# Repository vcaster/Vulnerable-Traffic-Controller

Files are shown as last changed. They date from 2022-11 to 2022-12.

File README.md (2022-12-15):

# Vulnerable-Traffic-Controller
## Overview
I built a simulated traffic network with traffic lights that mimics the real world. In addition to the simulation, I created a model train station controlled by traffic lights to illustrate the disaster that occurs when the traffic network is attacked and successfully exploited. The attack was the collision of two trains. Traffic control systems are widely used worldwide to optimize traffic flow, and threat actors can leverage vulnerable systems to cause accidents and disrupt emergency services.
A web interface was built to display varying traffic flow, and a power switch is needed for a traffic operator specialist to perform their role.
The simulated traffic control system was built with a siemens s7 1200 PLC, housing the logical functions of the environment. In addition, an Arduino is attached with an Ethernet Shield w5100, Infrared obstacle avoidance sensors, model trains, and a model railway.

# Paper
* [Building and attacking a traffic controller.pdf](https://github.com/vcaster/Vulnerable-Traffic-Controller/blob/main/Building%20and%20attacking%20a%20traffic%20controller.pdf)
# Images
### Live Action
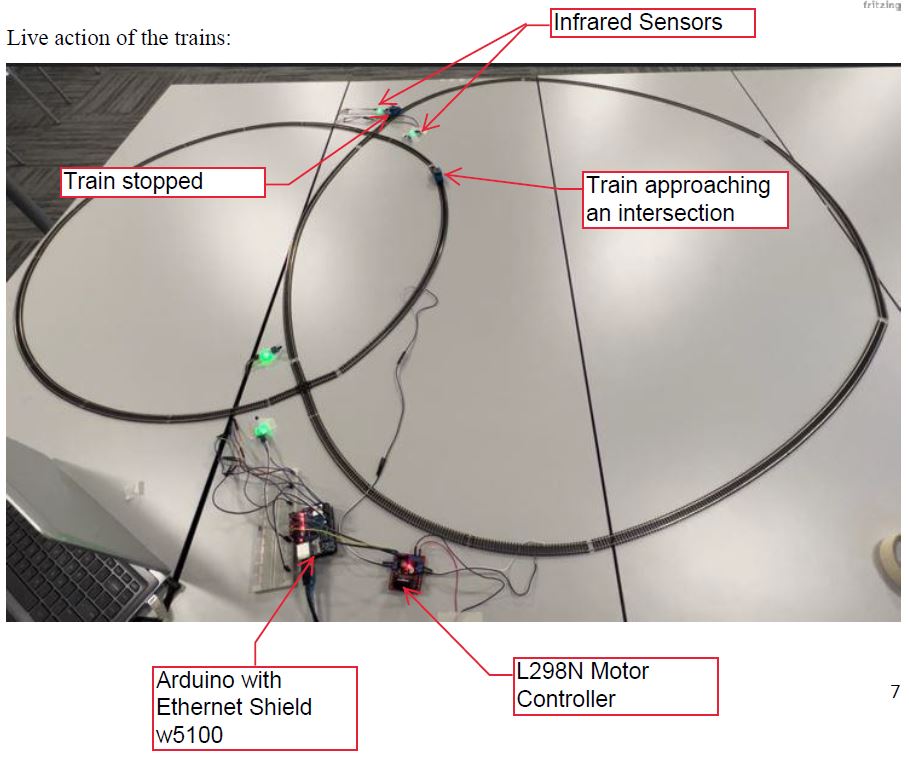
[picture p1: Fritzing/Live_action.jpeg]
Live Action


### PLC Sketch
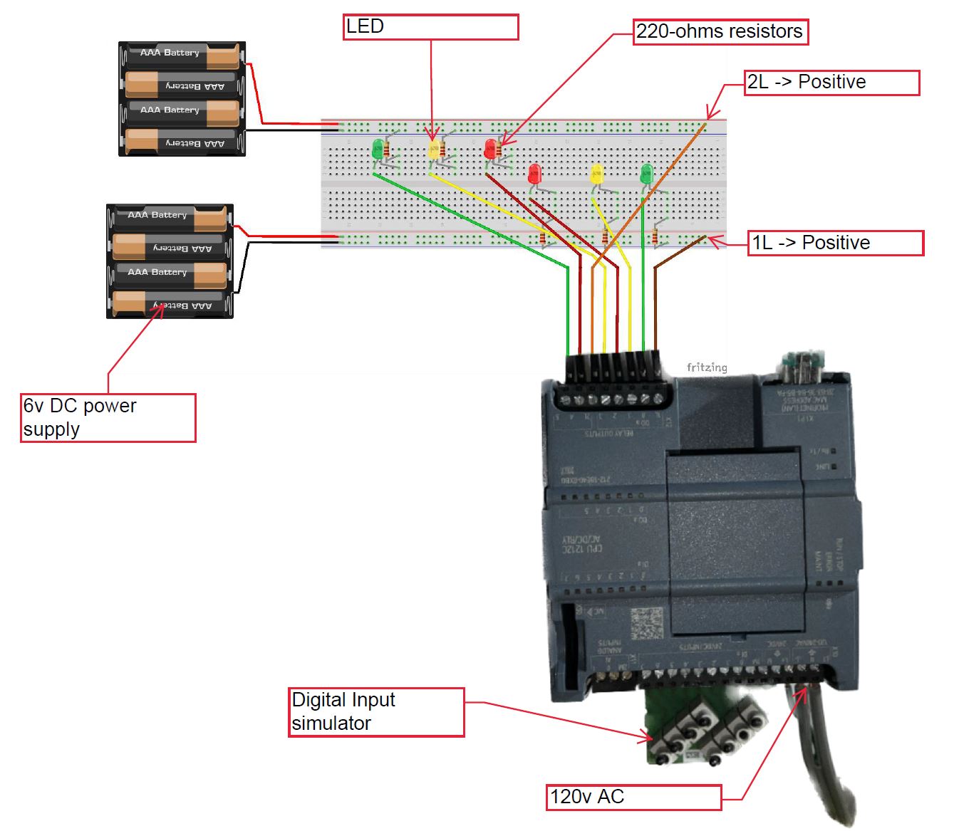
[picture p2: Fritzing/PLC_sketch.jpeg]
PLC Sketch


### Arduino Sketch
PLC Sketch
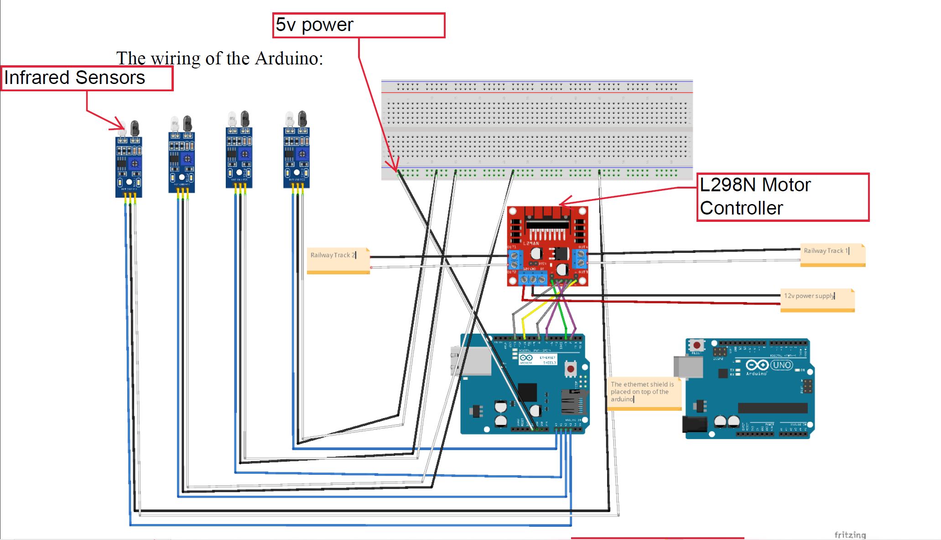
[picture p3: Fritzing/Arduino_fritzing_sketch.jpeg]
Arduino Sketch


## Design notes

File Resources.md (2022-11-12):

# Siemens PLC 

## Programing

* Siemens S7-1200 Video Training Series https://www.youtube.com/playlist?list=PLXgzIIGmsGipySUhEn11-RFaotanAtalO

* Traffic Lights Using PLC Programming https://www.youtube.com/watch?v=mFSuzfGuTHk&t=1s
*

## Modbus

* https://onping.net/bringing-a-siemens-s7-plc-in-to-onping-as-a-modbus-server/
* https://www.solisplc.com/tutorials/modbus-tcp-communications-in-siemens-tia-portal
* https://www.youtube.com/watch?v=POast2vW97A
* https://www.youtube.com/watch?v=6qLv_J2Dk1s
* https://www.youtube.com/watch?v=cjSm5qJfmPg
* https://www.youtube.com/watch?v=NwzBaDsGpic

# Arduino

* Automated Model Train With An Arduino https://www.youtube.com/watch?v=PoOxFS2DNpI&list=WL&index=5&t=8s

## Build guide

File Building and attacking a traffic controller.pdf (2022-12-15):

# Building and attacking a traffic controller:

# SCADA

### Ezekiel O. Aina

### Department of Computer & Information Sciences

### Towson University

### Towson, MD 21252

eaina1@students.towson.edu

Table of Contents

# Overview

The ICS/SCADA industry has been a target for nation-state campaigns, and the need to

understand the attack vector was the goal of this project. I built a simulated traffic network with

traffic lights that mimics the real world. In addition to the simulation, I created a model train

station controlled by traffic lights to illustrate the disaster that occurs when the traffic network is

attacked and successfully exploited. The attack was the collision of two trains. Traffic control

systems are widely used worldwide to optimize traffic flow, and threat actors can leverage

vulnerable systems to cause accidents and disrupt emergency services.

A web interface was built to display varying traffic flow, and a power switch is needed for a

traffic operator specialist to perform their role.

The simulated traffic control system was built with a siemens s7 1200 PLC, housing the logical

functions of the environment. In addition, an Arduino is attached with an Ethernet Shield w5100,

Infrared obstacle avoidance sensors, model trains, and a model railway.

Over the course of this project, I concluded that the MODBUS protocol is insecure, and I

recommend that the protocol be switched to one that includes more layers of security. And if the

system using the MODBUS protocol is a legacy system, then the system must be air-gaped and

layered to restrict access to critical devices.

# Hardware setup

The PLC used for the project is the Siemens SIMATIC S7-1200 (CPU 1212C AC/DC/RLY).

The first PLC is the server updating the traffic sequence and the second acts as a client that syncs

the traffic sequence. I wired the PLC with two sets of traffic lights mapped to the output

addresses on the PLC. The PLC outputs are just relays, and the Orange and brown wires (1L, 2L)

are plugged into positive to complete the circuit. While outputs 0 - 5 are mapped to the green,

yellow, and red lights. The breadboard is powered via a 6v power supply with 220-ohm resistors attached to each LED, and the PLC is powered by 120v. When we get to the software section,

we'll go into how the lights are turned on and the logic behind the timing.

The wiring of the PLC (they are the same for the server and client)

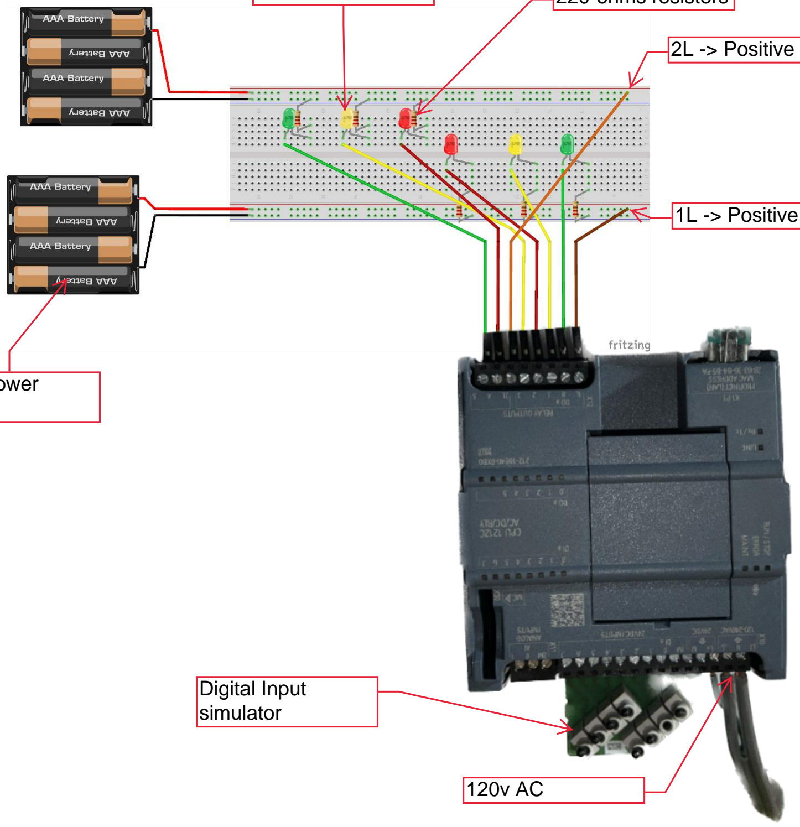
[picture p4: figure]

I faced the problem of simulating the system’s moving parts, which made me consider a remote-

controlled motor with wheels, but the margin of error would be substantial. I finally settled on model trains because it was feasible to control and to forge a path with the railway tracks. Once

the locomotive unit was decided, I needed a device to read the PLC server's traffic sequence. The

Arduino Uno was chosen because it supports many input and output devices. Still, the Arduino

Uno, by default, does not have network capabilities. To achieve that, we need to attach the

Ethernet Shield w5100, an Ethernet attachment for the Arduino.

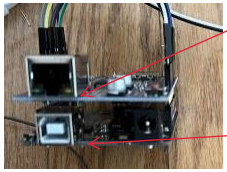
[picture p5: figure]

The Arduino uses an infrared sensor that lets the Arduino know when a train is passing, the black

wire is connected to the negative, the white is connected to the positive, and the blue is

connected to an analog input pin on the Arduino, which gives a value less than 500 each time it

senses motion.

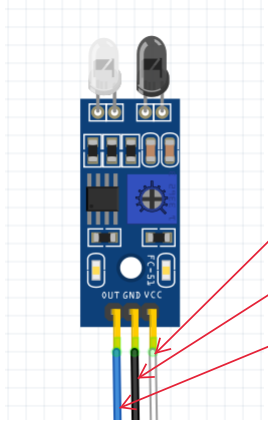
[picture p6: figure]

The blue wires on the analog inputs of the Arduino come from each infrared sensor located at

each stop, and the white and black wires power the breadboard, positive and negative,

respectively. Another critical component that moves the train is the L298N motor controller,

which has four outputs connected to the outside of the railway, a 12v power supply (Red and

black wires), two analog inputs (ENA, ENB) that set the speed (Green and Yellow wires) and

four digital inputs (Grey and Purple wires). The L298N motor controller supplies power to the

railway when inputs 1 and 2 or inputs 3 and 4 receive a (High, Low) signal from the Arduino,

and to stop the trains, they receive a (Low, Low) signal.

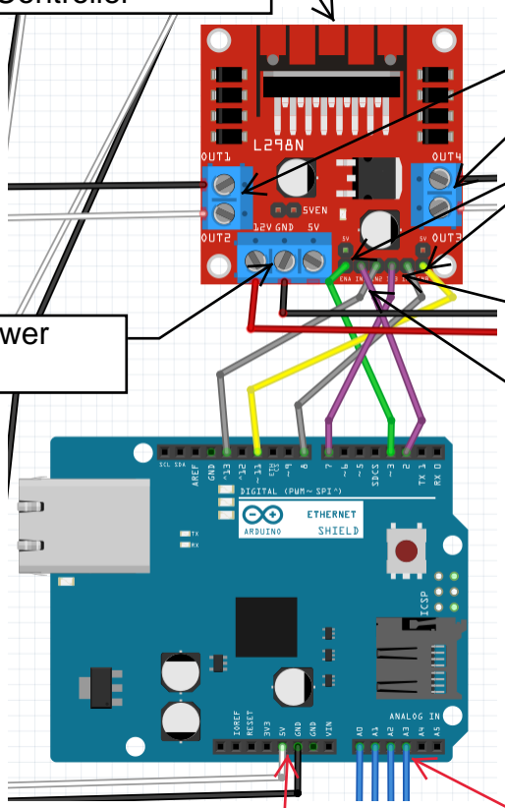
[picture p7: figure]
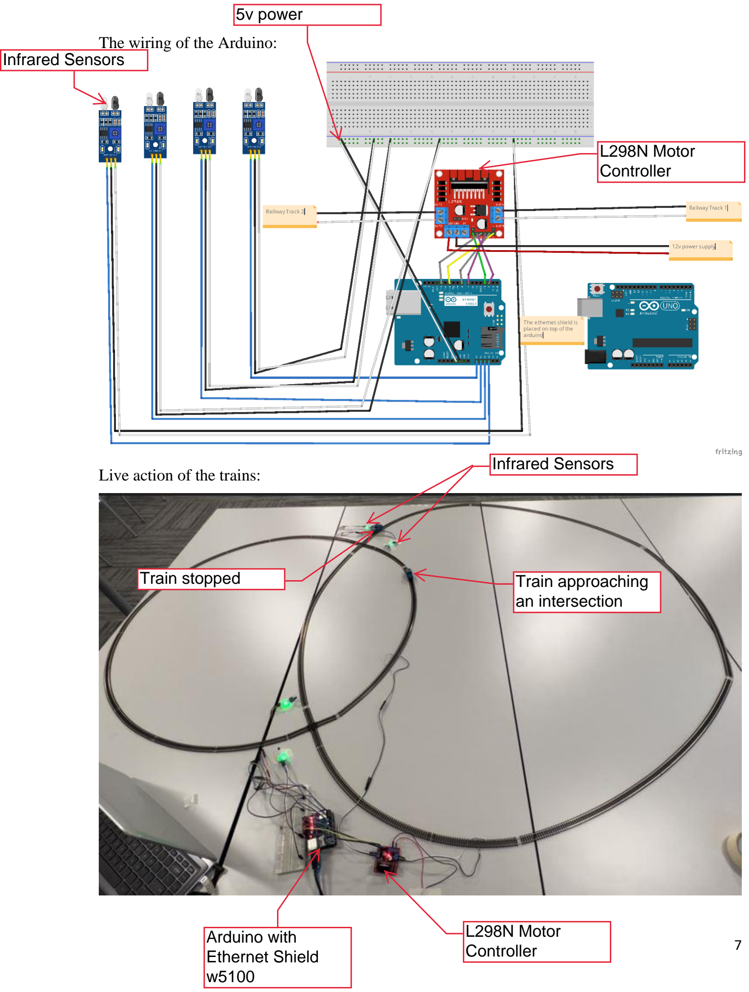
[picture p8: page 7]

The wiring of the Arduino:

Live action of the trains:

# Network setup

Taking a network view, we can consider the connected devices on the network, and the ports

used. Building the network involves a router with the range 10.10.0.0/16 attached to a switch.

Then, PLC 1 (Server listening on ports 502,503, and 504), PLC2, the Arduino, and the

workstation are assigned their respective IP address.

The devices are connected via an Ethernet cable (rj45)

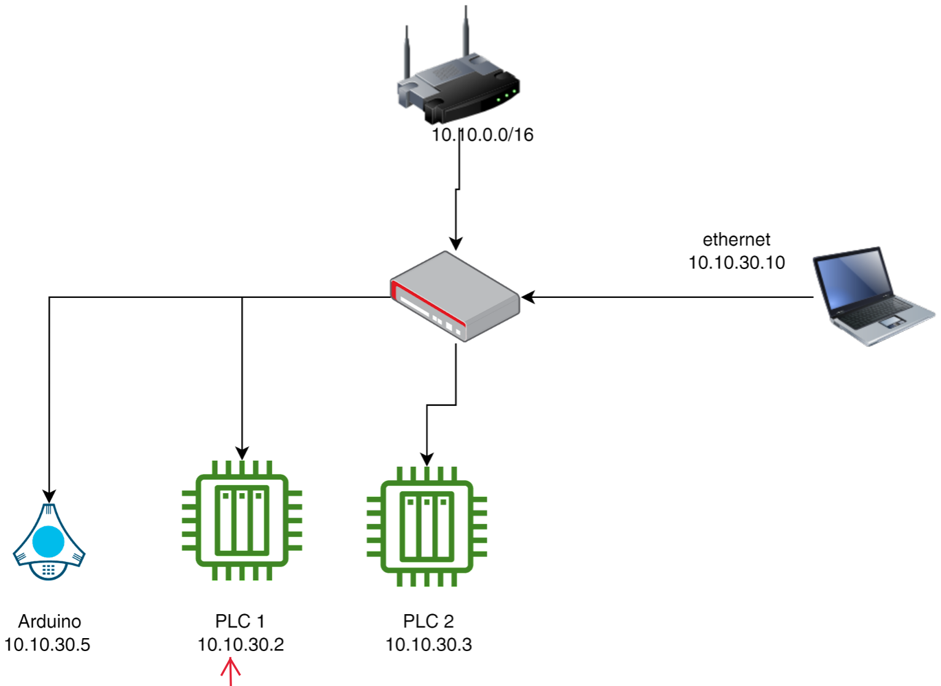
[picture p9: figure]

# Software

## Siemens PLC

Importing Project files

To program a Siemens PLC, we need a windows seven workstation with the TIA portal v14

installed. The project files used can be imported from the GitHub link. (https://github.com/vcaster/Vulnerable-Traffic-Controller) Copy the project folder to

the project directory, usually in 'C:\Users\<username>\Documents\Automation'. On the Start

page of the TIA Portal, browse and navigate to the 'Traffic_Control.ap14` file. Once it has

loaded, click on 'Project View' at the bottom left of the screen.

## Programming logic

PLC tags

The primary use of PLC tags is to attach names to an address to be called and used. The switches

are attached to the input address %I0.0 - %I0.7, the lights are attached to the output address

%Q0.0 - %Q0.5, the memory address %M0.0 - %M0.1 holds the delay bit for the traffic

sequence, and the rest are system generated (General -> pulse generator -> enable system and

clock memory byte). These tags will be referenced later when building the traffic logic.

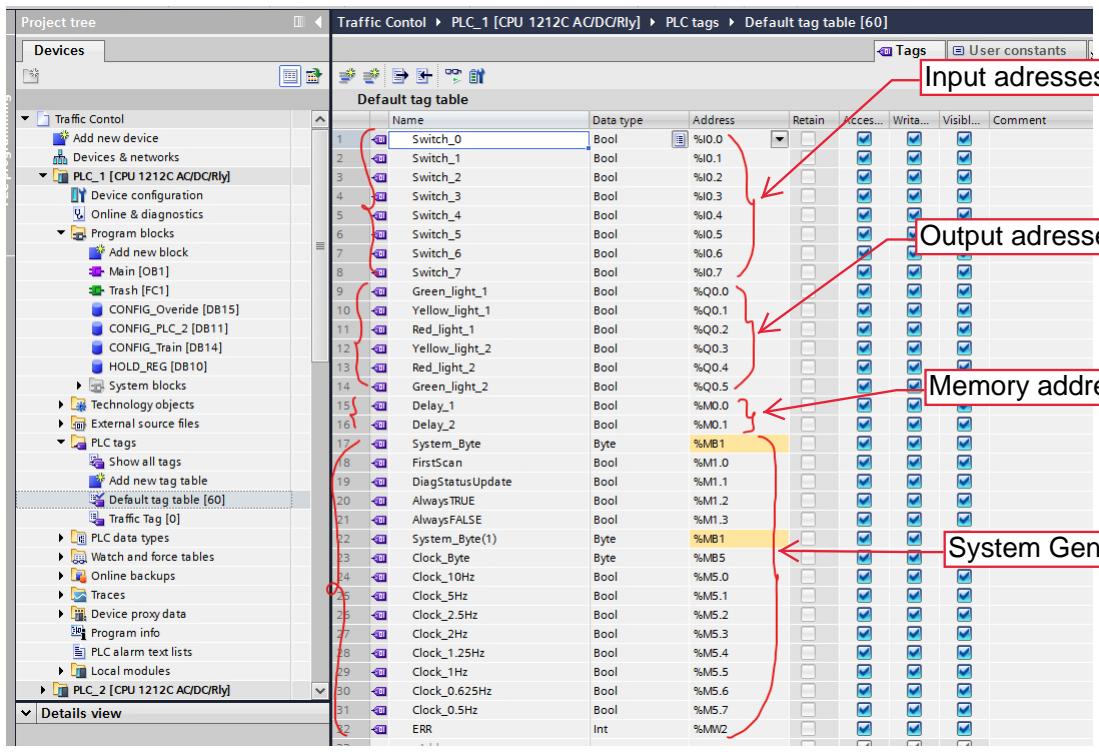
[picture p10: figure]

PLC 1 (Server)

I faced many options for communication between PLCs, but I settled on MODBUS because of

its popularity in SCADA/ICS devices. The main program block contains all the logic

implemented on PLC 1, including MODBUS server logic, Traffic timer sequence, and web

interface configurations. Each piece of logic is in its network in the main program block.

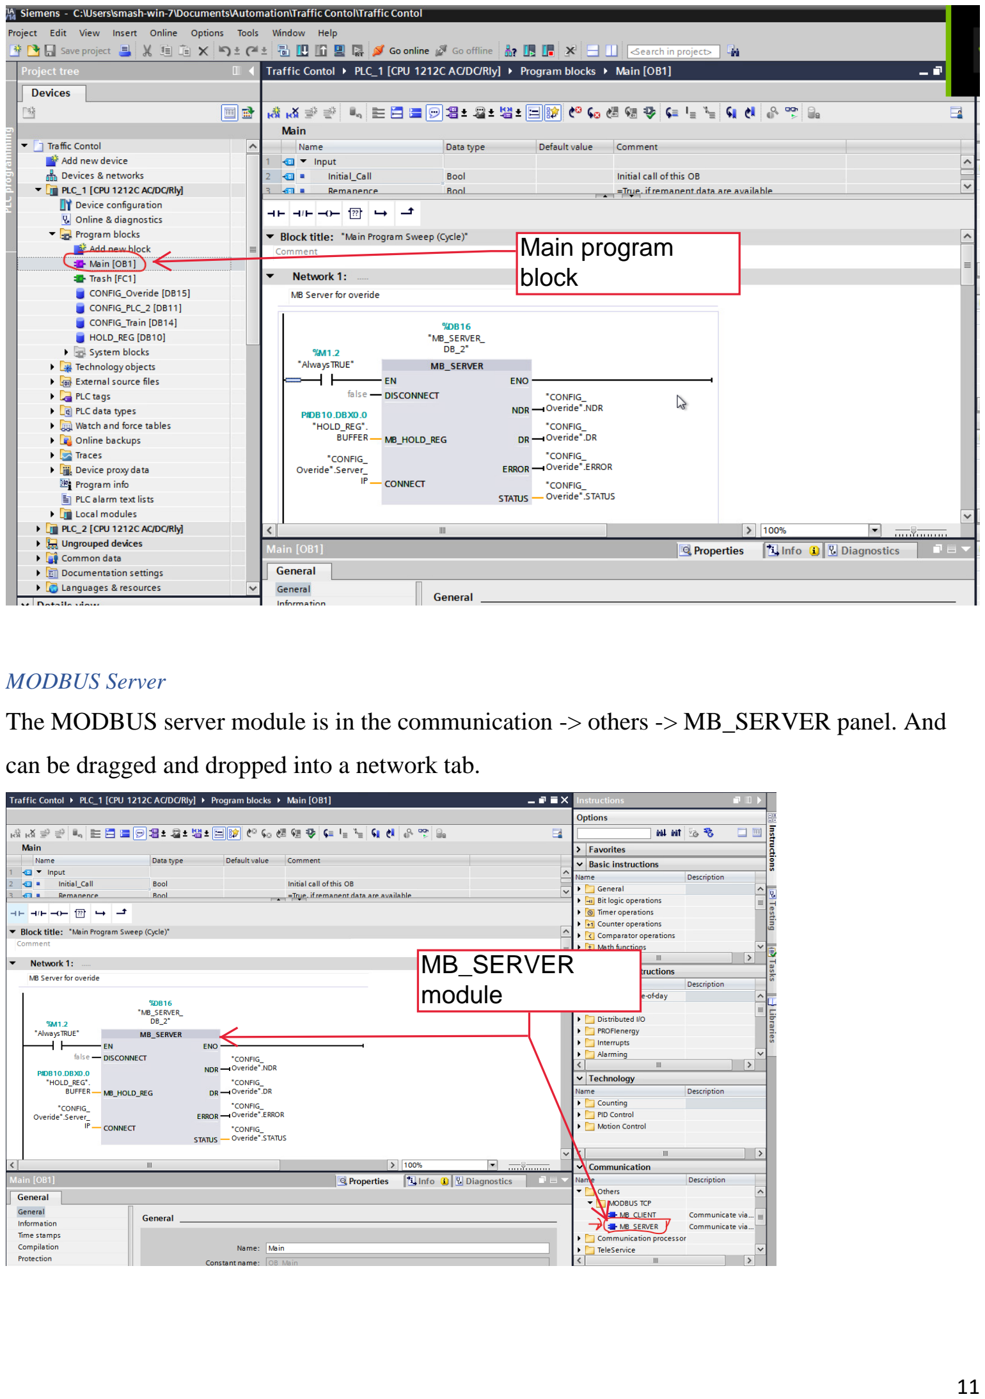
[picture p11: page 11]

MODBUS Server
The MODBUS server module is in the communication -> others -> MB_SERVER panel. And

can be dragged and dropped into a network tab.

A server configuration data block is created and mapped to the MB_SERVER module.

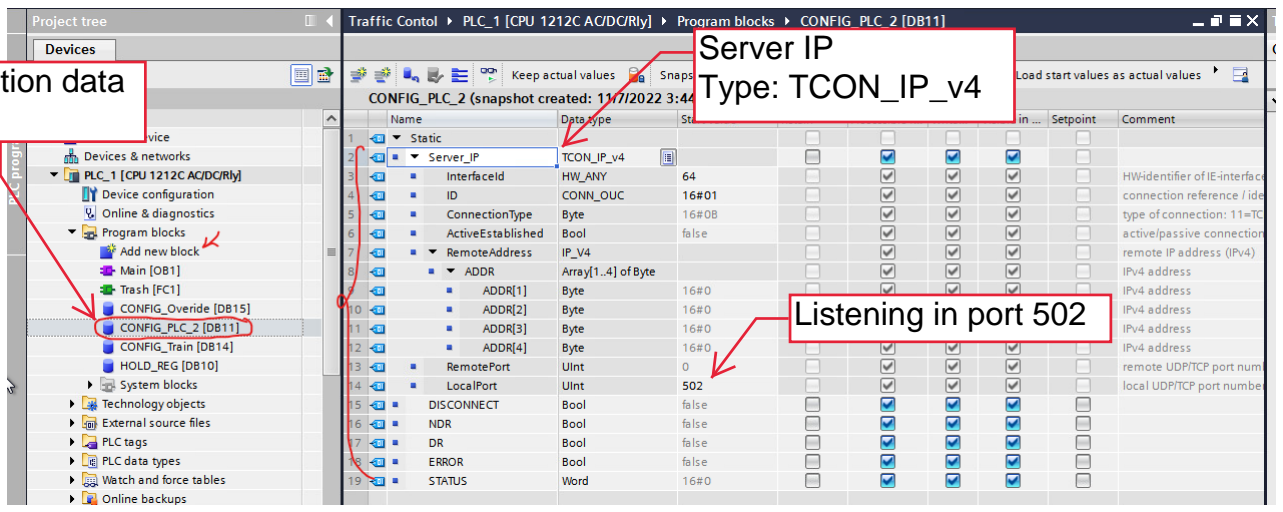
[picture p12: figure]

The MB_HOLD_REG on the MB_SERVER module needs a data block synced with any

connected client, representing a database shared among the PLC. This is how we have the client

receive the traffic signals. The configuration for the buffer is an array of bool (0-15) representing

each bit in a holding register. Under the properties of the buffer array, the "optimize block

access" is checked off so that we can get an absolute address for the buffer array, e.g.

(%DB10.DBX0.0)

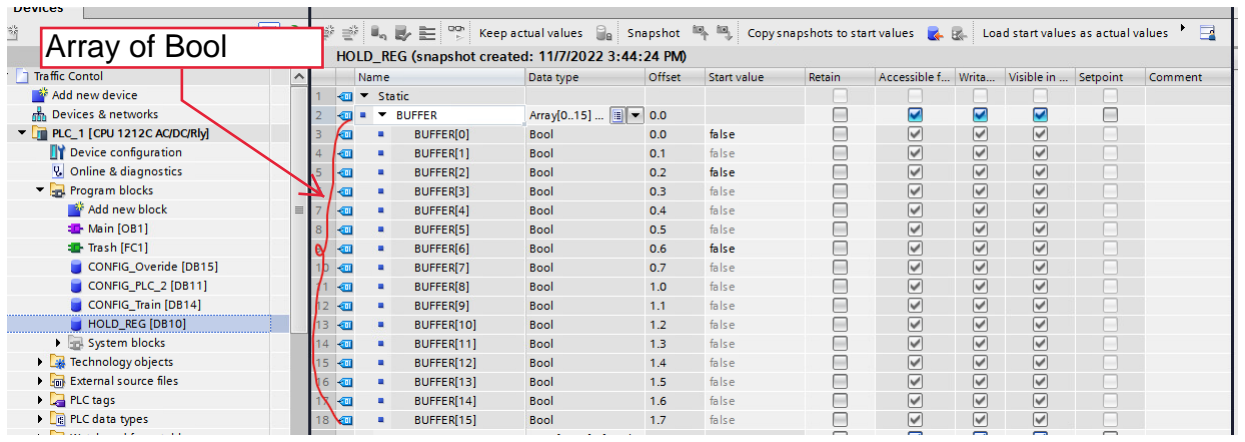
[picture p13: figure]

Traffic sequence
The programming of the traffic sequence is done with "ladder logic," a standard style for

programming PLCs. Ladder logic uses lines coupled with switches and modules to represent how

the inputs and outputs behave. For an in-depth explanation of ladder logic and its modules,

reference this playlist on youtube. (https://www.youtube.com/playlist?list=PLXgzIIGmsGipySUhEn11-RFaotanAtalO)

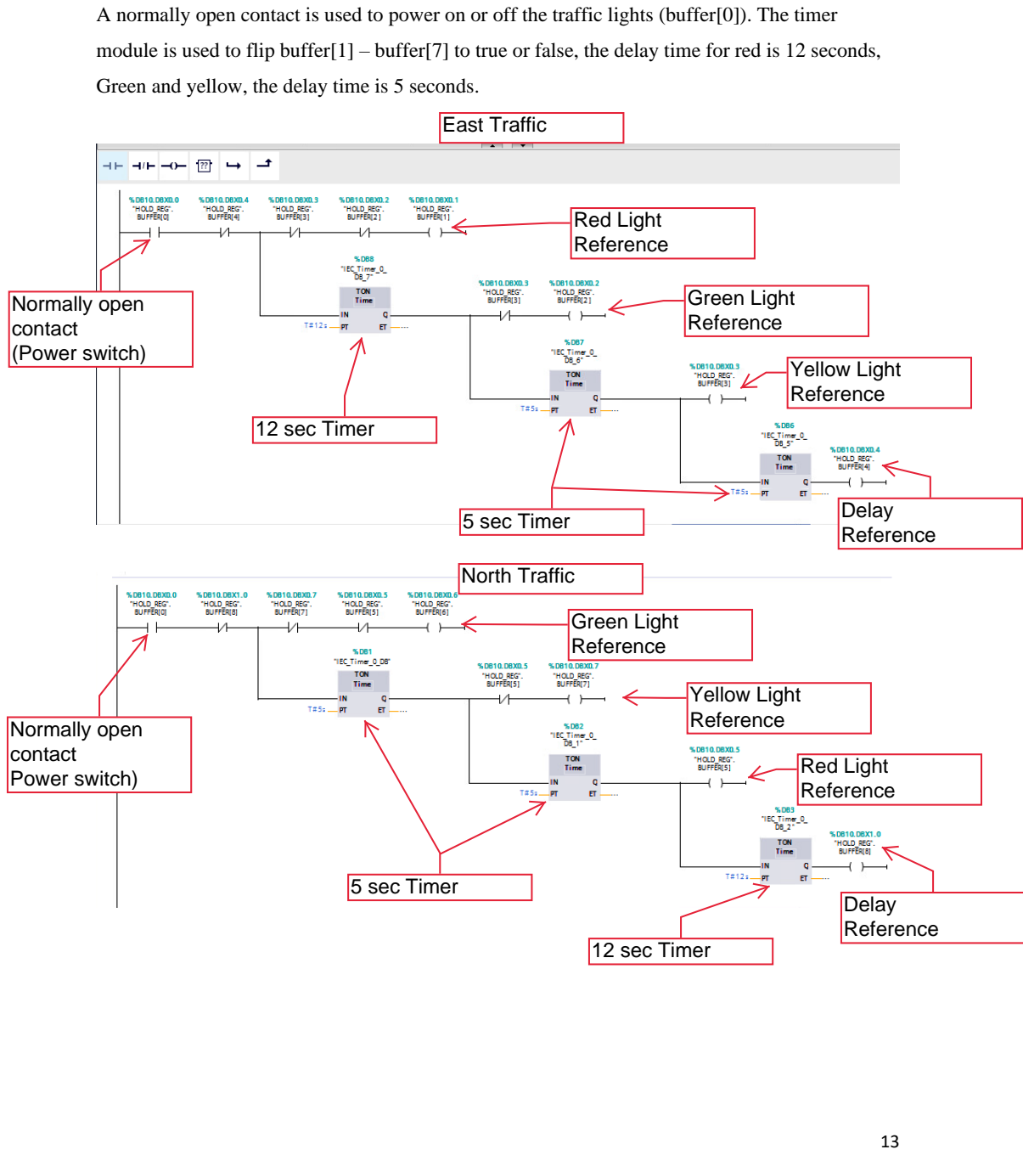
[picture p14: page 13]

A normally open contact is used to power on or off the traffic lights (buffer[0]). The timer

module is used to flip buffer[1] – buffer[7] to true or false, the delay time for red is 12 seconds,

Green and yellow, the delay time is 5 seconds.

The mapping for each bit in the holding register is as follows:

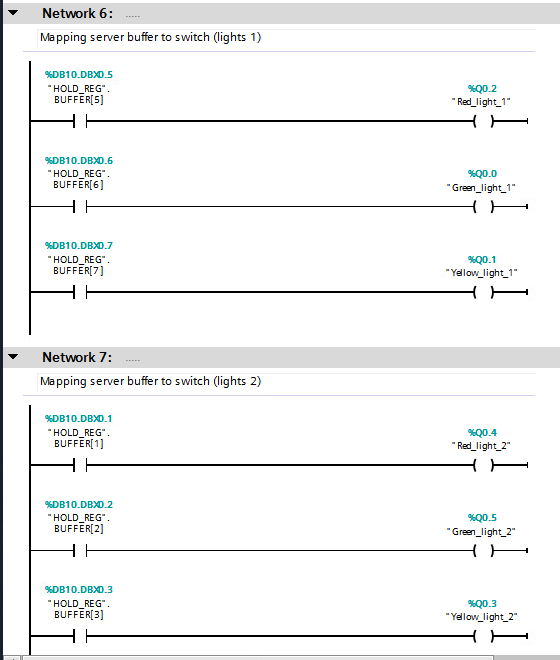
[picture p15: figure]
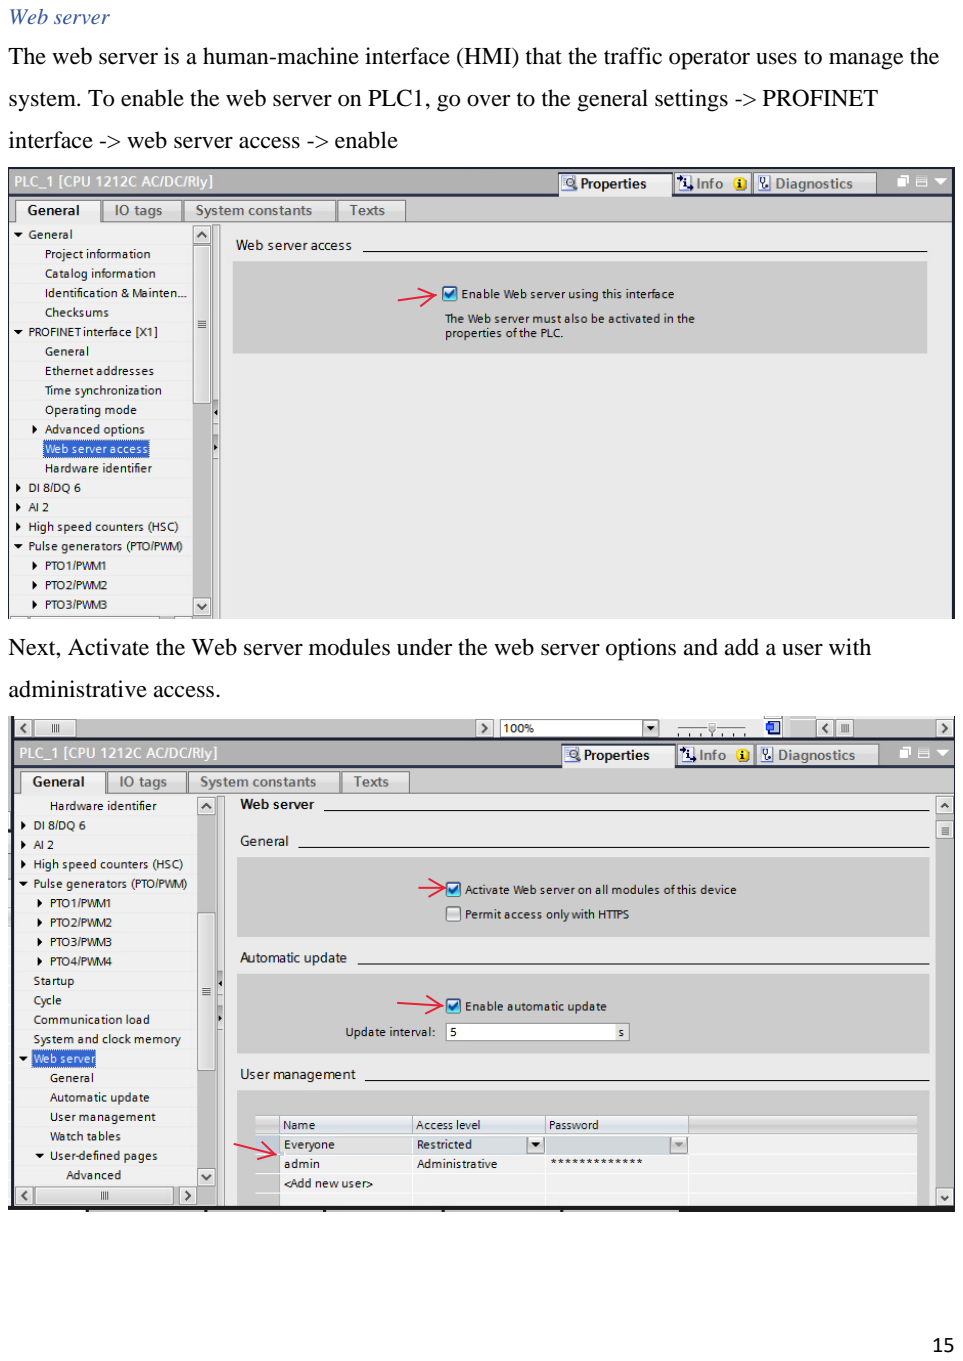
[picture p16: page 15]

Web server
The web server is a human-machine interface (HMI) that the traffic operator uses to manage the

system. To enable the web server on PLC1, go over to the general settings -> PROFINET

interface -> web server access -> enable

Next, Activate the Web server modules under the web server options and add a user with

administrative access.

Under the User-defined pages, set the HTML directory as .\Webserver and the Default HTML

page as index_preweb.html, then generate blocks. This adds a data block that the web server can

use.

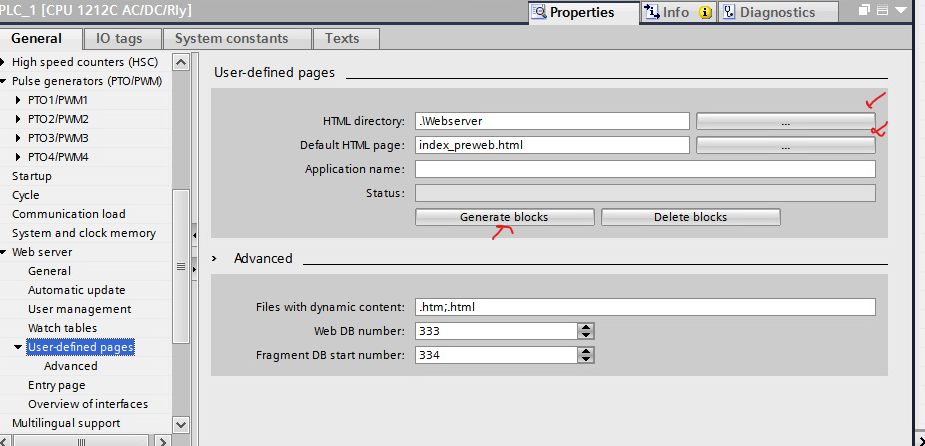
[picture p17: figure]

Add a network with the WWW module on the main block and use the generated blocks

%DB333, which was generated when the HTML page was imported.

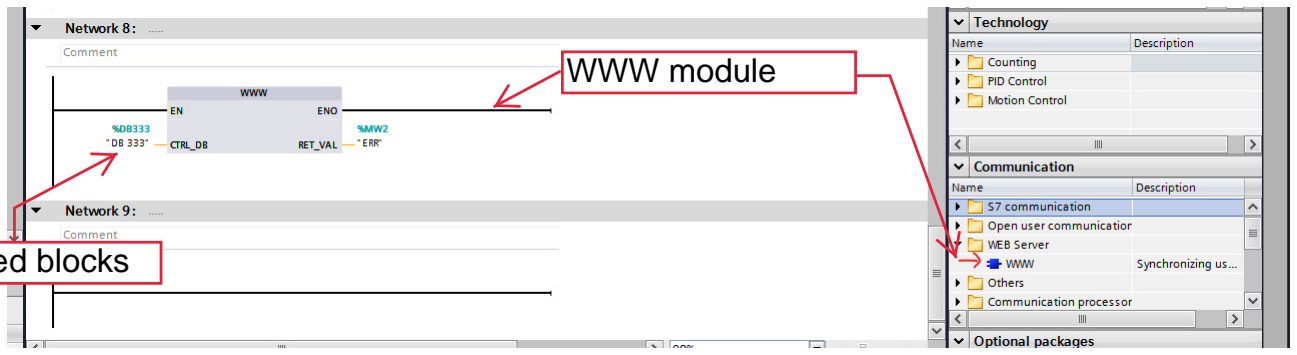
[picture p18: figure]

Web page
Siemens user-defined page uses a template-like engine to map data blocks variables in HTML.

First, the variable has to be declared in an HTML comment before being displayed on the page.

Then, the variable is wrapped in a form tag with a hidden input tag containing the value that

should be set before it can be modified, as seen below.

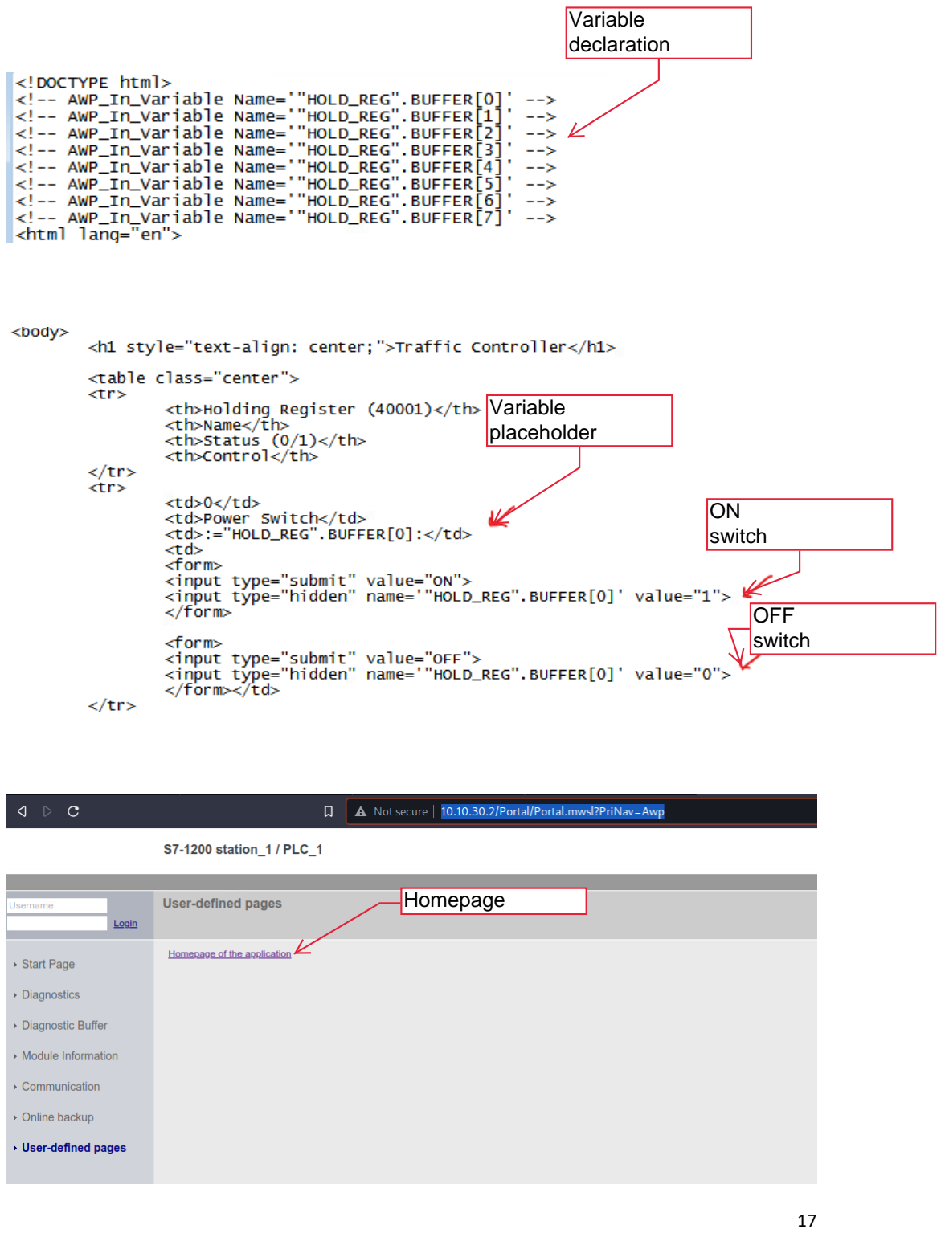
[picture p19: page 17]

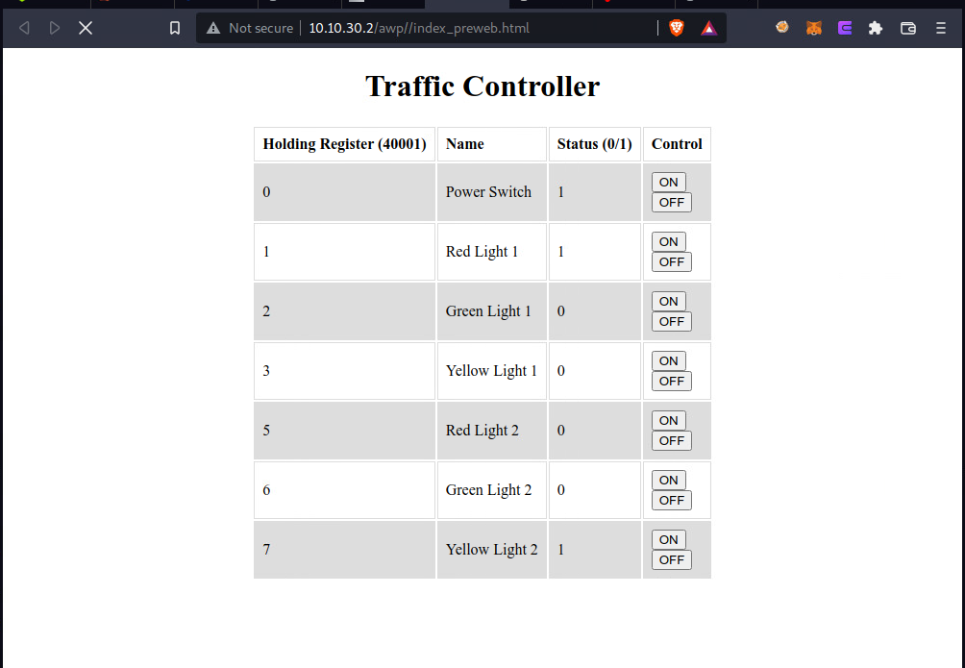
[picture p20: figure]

PLC 2 (Client)

The job of the client PLC is to read the holding registers from the server and map the results to

their outputs. The MB_CLIENT module is used with the following settings, MB_MODE is set to

0 for read-only, the MB_DATA_ADDR is set to 40001 for the first address in the holding

register, and MB_DATA_LEN is set to 1, meaning it should only read address 40001.

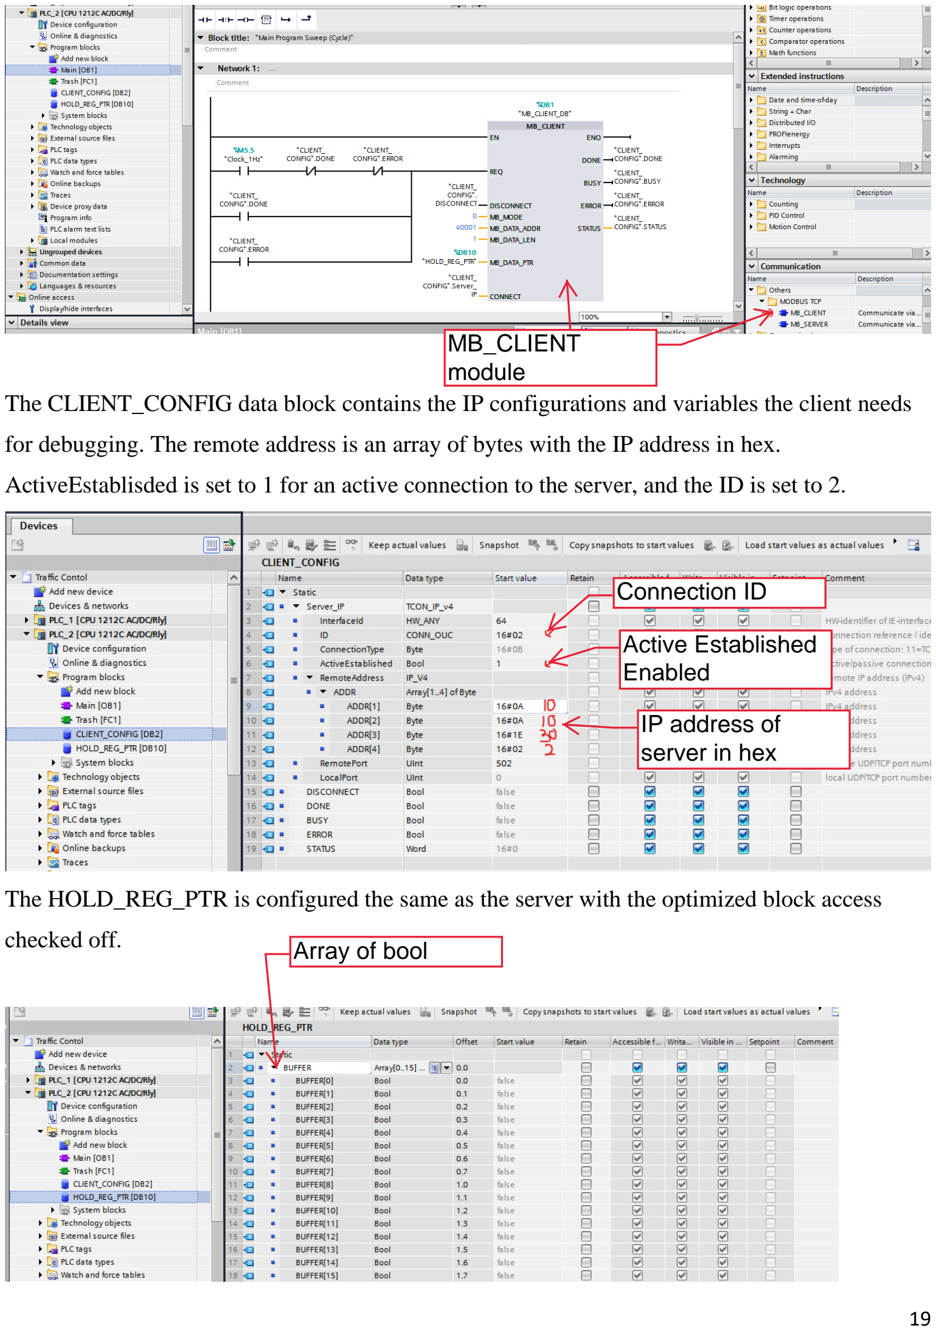
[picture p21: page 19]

The CLIENT_CONFIG data block contains the IP configurations and variables the client needs

for debugging. The remote address is an array of bytes with the IP address in hex.

ActiveEstablisded is set to 1 for an active connection to the server, and the ID is set to 2.

The HOLD_REG_PTR is configured the same as the server with the optimized block access

checked off.

## Arduino

The libraries needed for the Arduino are called "ArduinoModbus" and "ArduinoRS485," which

can be installed from the Arduino sketch book (press ctrl + shift + I). The Arduino sketch book is

where the Arduino UNO is programmed by uploading a compiled code to the Arduino UNO

connected via a USB com port.

The code running on the Arduino uses the Infrared obstacle avoidance sensor to determine if the

model train is approaching an intersection. The Arduino runs in a constant loop that reads the

MODBUS holding register at address 40001 from PLC 1 and checks if the train is about to

approach a stop signal. Finally, according to the MODBUS data, a condition stops the north or

east traffic, which sends the correlating signals to the motor driver controlling the railway.

Arduino converts the 16-bit holding register to decimal:

16-bit register (binary) | Decimal | Traffic Sequence
0100001100000000 | 17152 | Red, Green
0010010100000000 | 9472 | Green, Red
0010100100000000 | 10496 | Yellow, Red
0111110100000000 | -32000 | Red, Yellow
0010001100000000 | 8960 | Red, Red

The Arduino sketch goes into more intricate details in its comments.

# Exploiting the system

A gray box penetration testing of the system will start with an enumeration of the server on

10.10.30.2. Enumeration is done with Nmap to gather information about the server and ports

open. The ports open are 80,443,102,504.

The arguments “-sC” runs default scripts for discovery, “-sV” tries to get the version of services

found, “-Pn” disables host discovery and does port scan only, and “-p” specifies the server IP

address.

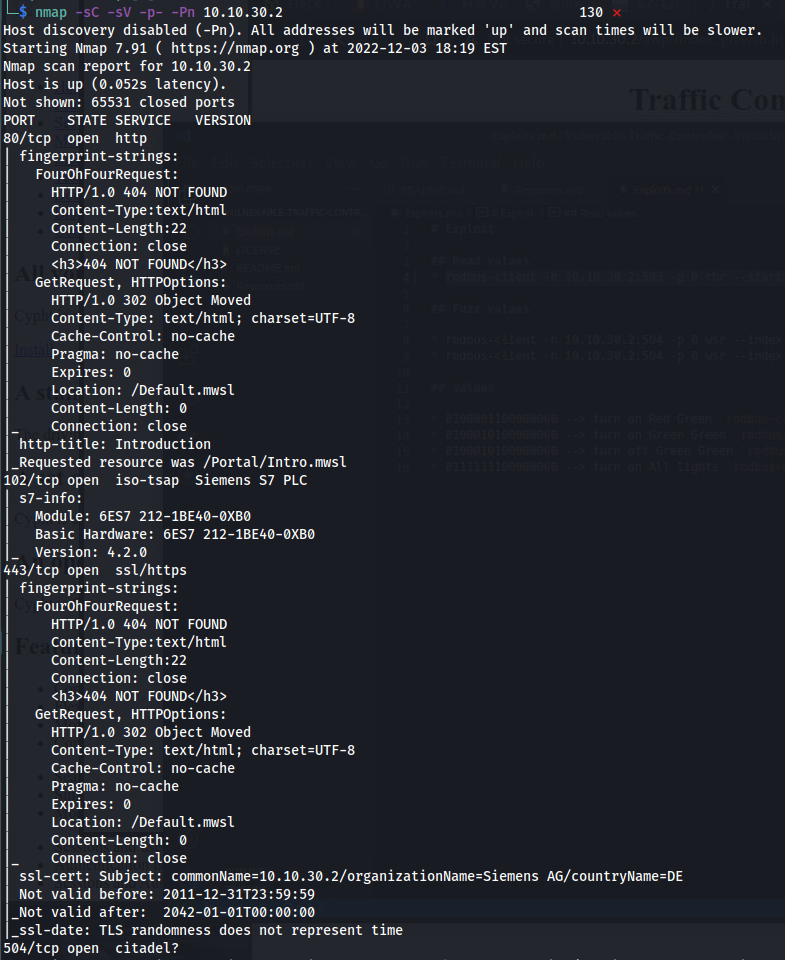
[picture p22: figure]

Port 102 reveals that the machine is a siemens plc when we proceed with the HTTP port 80.

We notice that the PLC gives us direct access to some of the controls. This is because the PLC

was misconfigured to grant access to everyone.

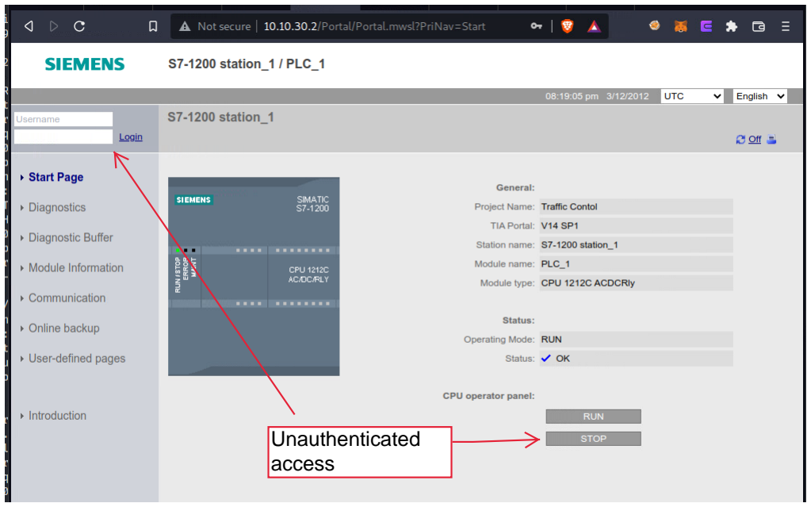
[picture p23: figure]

Trying a weak password admin:admin grants us administrative access.

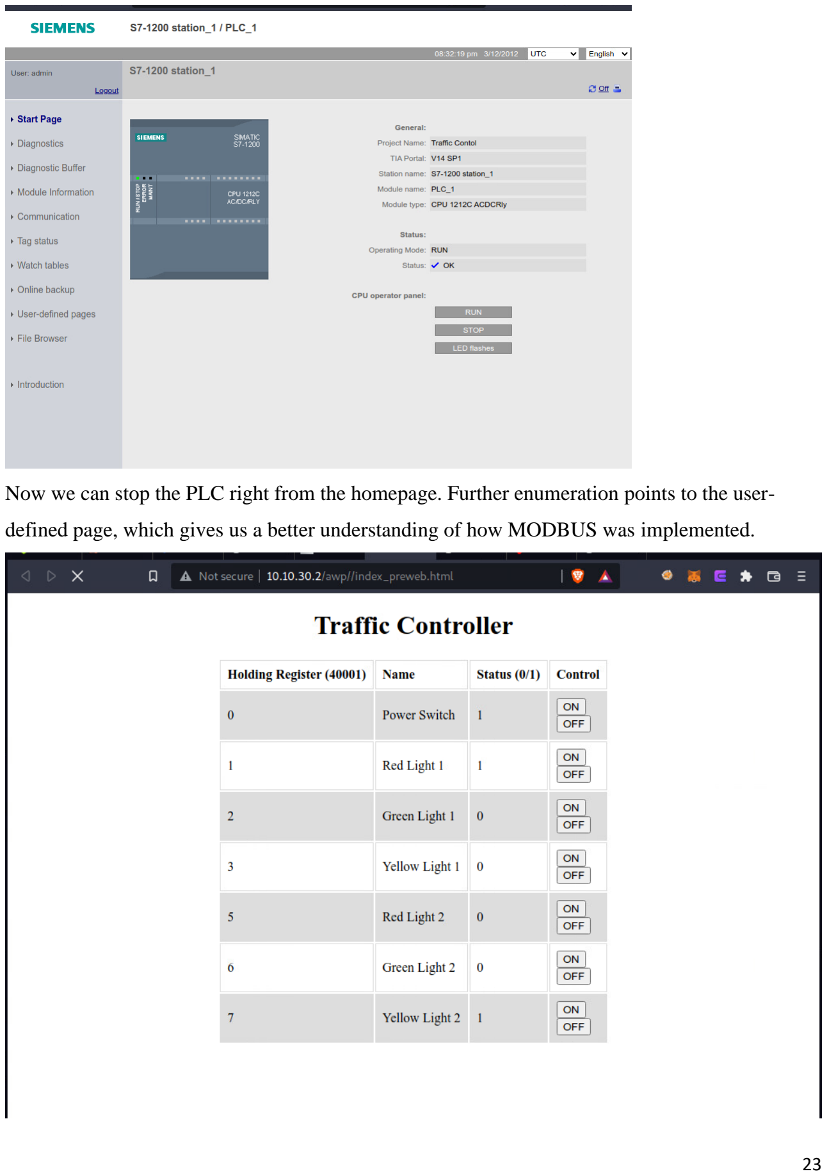
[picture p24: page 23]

Now we can stop the PLC right from the homepage. Further enumeration points to the user-

defined page, which gives us a better understanding of how MODBUS was implemented.

The holding register 40001 holds the power switch and all the lights. We need to overwrite the

holding register constantly to alter the system's behavior. Because of the enumeration done, we

could use port 504. The tool is called “rodbus-client,” a command line tool used to interact with

a MODBUS server.

The following are the commands issued to alter the lights:

1. “rodbus-client -h 10.10.30.2:504 -p 0 wsr --index 0 --value 17408” : Turns all

green lights

2. “rodbus-client -h 10.10.30.2:504 -p 0 wsr --index 0 --value 0”: Switches the

system off

3. “rodbus-client -h 10.10.30.2:504 -p 0 wsr --index 0 --value 32512” : Turns all

lights on

“-p 0” sets the polling period to 0 milliseconds, “wsr” sets the mode to write to holding registers,

“--index 0” means the first register (40001), “--value XXXX” sets the binary equivalent in

decimal to the register.

With the attack that turns all lights green, the train would eventually collide because the normal

traffic flow had been overwritten.

# Challenges Faced

Throughout the project, some hurdles required more research or a simpler alternative.

Siemens

1. The learning curve for the workflow of programming a Siemens PLC is pretty high, but

with the right resources, like this playlist on youtube, (https://www.youtube.com/playlist?list=PLXgzIIGmsGipySUhEn11-RFaotanAtalO) learning was smooth.

2. The reason for multiple ports for the MODBUS protocol was to make testing easy.

Arduino

1. The ethernet module was not working until pin four was declared as an output.

2. The output pins marked with "~" also known as pulse width modulation (PWM), are

unsuitable for sending the off signal to cut power to the model trains. The resolution was

to exclude the output pins with PWM enabled

# Appendix

## Hardware Requirements

The essential hardware requirements to replicate this project includes the following:

1. Router
2. Switch (optional)
3. 2 PLCs (Siemens SIMATIC S7-1200) (CPU 1212C AC/DC/RLY)
4. Arduino Uno
5. UnoL298N motor drive controller
6. Ethernet Shield w5100
7. Infrared obstacle avoidance sensor (4 pcs)
8. LEDs (Red, Yellow, Green) (4pcs each)
9. 220 ohms resistors (12 pcs)
10. Windows 7 workstation
11. 2 Model trains (scale N)
12. Model railway (scale N)
1. Atlas 2569 Code 80 90 Degree Crossing (2 pcs)
2. Atlas 2500 Black Code 80 Super-Flex 30" Track Section (6 pcs)
3. Atlas 2525 Code 80 17" RADIUS TRACK - (6 pcs)
4. Atlas #2535 Code 80 Track Rail Joiners (20 pcs)
5. Plier
13. American Tool Group #11538 8" diagonal plier
14. Ethernet cable (rj45) (4pcs)
15. Dupont Wires (m-f,f-f,m-m) (60 pcs)
16. Raspberry pi (3/4) or 5v power supply (2pcs)
17. 12v power supply (110v to 12 volt)

## Software requirements

The essential software requirements to replicate this project include the,

1. TIA portal v14
2. Arduino sketch book

## Project Files

The project files are hosted on GitHub, (https://github.com/vcaster/Vulnerable-Traffic-Controller) including the saved project from the TIA portal, the

sketch book used in programming the Arduino, and other resources used in developing this

project.

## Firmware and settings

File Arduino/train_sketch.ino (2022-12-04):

#include <SPI.h>
#include <Ethernet.h>

#include <ArduinoRS485.h>  // ArduinoModbus depends on the ArduinoRS485 library
#include <ArduinoModbus.h>

// Enter a MAC address for your controller below.
// Newer Ethernet shields have a MAC address printed on a sticker on the shield
// The IP address will be dependent on your local network:
byte mac[] = {
  0xDE, 0xAD, 0xBE, 0xEF, 0xFE, 0xED
};
IPAddress ip(10, 10, 30, 10); // assignes the arduino an IP address

int eastStop1;
int eastStop2;
int northStop1;
int northStop2;

int holdReg;
int Speed = 255;

EthernetClient ethClient;
ModbusTCPClient modbusTCPClient(ethClient);

IPAddress server(10, 10, 30, 2);  // IP Address of your Modbus server
void start() {
  // Starts all movement which sends the signal to the motor driver
  digitalWrite(2, HIGH);
  digitalWrite(13, LOW);
  digitalWrite(7, LOW);
  digitalWrite(8, HIGH);
}
void stopEastT() {
  //Stops east traffic which sends the signal to the motor driver
  digitalWrite(7, LOW);
  digitalWrite(8, LOW);
}

void stopNorthT() {
  //Stosp north traffic which sends the signal to the motor driver
  digitalWrite(2, LOW);
  digitalWrite(13, LOW);
}
void setup() {
  //Initialize serial and wait for port to open:
  Serial.begin(9600);
  // while (!Serial) {
  //   ; // wait for serial port to connect. Needed for native USB port only
  // }

  // disable SD SPI
  pinMode(4, OUTPUT);
  digitalWrite(4, HIGH);


  pinMode(3, OUTPUT); // declare pin 3 used by the motor driver to set the speed
  pinMode(11, OUTPUT); // declare pin 11 used by the motor driver to set the speed
  pinMode(2, OUTPUT); // declare pin 2 used by the motor driver to power the North traffic
  pinMode(13, OUTPUT); // declare pin 13 used by the motor driver to power the North traffic
  pinMode(7, OUTPUT); // declare pin 7 used by the motor driver to power the East traffic
  pinMode(8, OUTPUT); // declare pin 7 used by the motor driver to power the East traffic

  // set speed
  analogWrite(3, Speed);
  analogWrite(11, Speed);

  start();

  // start the Ethernet connection and the server:
  Ethernet.begin(mac, ip);

  // Check for Ethernet hardware present
  Serial.println(Ethernet.hardwareStatus());
  if (Ethernet.hardwareStatus() == EthernetNoHardware) {
    Serial.println("Ethernet shield was not found.  Sorry, can't run without hardware. :(");
    while (true) {
      delay(1);  // do nothing, no point running without Ethernet hardware
    }
  }
  if (Ethernet.linkStatus() == LinkOFF) {
    Serial.println("Ethernet cable is not connected.");
  }
}

void loop() {
  if (!modbusTCPClient.connected()) {
    // client not connected, start the Modbus TCP client
    Serial.println("Attempting to connect to Modbus TCP server");

    if (!modbusTCPClient.begin(server, 503)) {
      Serial.println("Modbus TCP Client failed to connect!");
    } else {
      //Serial.println("Modbus TCP Client connected");
    }
  } else {
    // client connected

    // read the value 0x00 == 40001

    if (!modbusTCPClient.holdingRegisterRead(0x00, 0x00)) {
      //Serial.println("Register returned 0 \n Stop all movement");
      //Serial.println(modbusTCPClient.lastError());

      start();

      // delay(10000);
    } else {
      //Serial.print("Holding Register");
      holdReg = modbusTCPClient.holdingRegisterRead(0x00);
      // Serial.println(holdReg); //prints the value of the holding registers in decimal

      // read the infraed sensors // any value less than 500 means the train is approaching an intersection
      eastStop1 = analogRead(A0);
      eastStop2 = analogRead(A1);
      northStop1 = analogRead(A2);
      northStop2 = analogRead(A3);

    // holdReg == 8960 means the traffic signal is RED, RED
      while (eastStop1 < 500 || eastStop2 < 500 || northStop1 < 500 || northStop2 < 500) {
        // read the infraed sensors
        eastStop1 = analogRead(A0);
        eastStop2 = analogRead(A1);
        northStop1 = analogRead(A2);
        northStop2 = analogRead(A3);
        if (holdReg == 8960 && (eastStop1 < 500 || eastStop2 < 500) && (northStop1 < 500 || northStop2 < 500)) {
          stopEastT();
          stopNorthT();
          holdReg = modbusTCPClient.holdingRegisterRead(0x00);
        }
        else if (holdReg == 8960 && (eastStop1 < 500 || eastStop2 < 500)) {
          stopEastT();
          stopNorthT();
          holdReg = modbusTCPClient.holdingRegisterRead(0x00);
        }
        else if (holdReg == 8960 && (northStop1 < 500 || northStop2 < 500)) {
          stopNorthT();
          holdReg = modbusTCPClient.holdingRegisterRead(0x00);
        } else {
          break;
        }
      }

      // Serial.println(eastStop1);

      // East
      // holdReg == -32000 means the traffic signal is RED, YELLOW
      // holdReg == 17152 means the traffic signal is RED, GREEN
      while (eastStop1 < 500) {
        eastStop1 = analogRead(A0);
        if (holdReg == -32000 || holdReg == 17152) {
          // Serial.println("stopped east1");
          stopEastT();
          holdReg = modbusTCPClient.holdingRegisterRead(0x00);
        } else {
          break;
        }
      }

      holdReg = modbusTCPClient.holdingRegisterRead(0x00);
      // read the infraed sensors
      eastStop1 = analogRead(A0);
      eastStop2 = analogRead(A1);
      northStop1 = analogRead(A2);
      northStop2 = analogRead(A3);

      while (eastStop2 < 500) {
        eastStop2 = analogRead(A1);
        if (holdReg == -32000 || holdReg == 17152) {
          // Serial.println("stopped east2");
          stopEastT();
          holdReg = modbusTCPClient.holdingRegisterRead(0x00);
        } else {
          break;
        }
      }

      //North
      // holdReg == 9472 means the traffic signal is GREEN, RED
      // holdReg == 10496 means the traffic signal is YELLOW, RED
      holdReg = modbusTCPClient.holdingRegisterRead(0x00);
      northStop1 = analogRead(A2);
      northStop2 = analogRead(A3);

      while (northStop1 < 500) {
        northStop1 = analogRead(A2);
        if (holdReg == 9472 || holdReg == 10496) {
          // Serial.println("stopped north1");
          stopNorthT();
          holdReg = modbusTCPClient.holdingRegisterRead(0x00);
        } else {
          break;
        }
      }

      holdReg = modbusTCPClient.holdingRegisterRead(0x00);
      northStop1 = analogRead(A2);
      northStop2 = analogRead(A3);

      while (northStop2 < 500) {
        northStop2 = analogRead(A3);
        if (holdReg == 9472 || holdReg == 10496) {
          // Serial.println("stopped north2");
          stopNorthT();
          holdReg = modbusTCPClient.holdingRegisterRead(0x00);
        } else {
          break;
        }
      }
    }

    // wait for 1 second
    start();
    // delay(500);
  }
}
